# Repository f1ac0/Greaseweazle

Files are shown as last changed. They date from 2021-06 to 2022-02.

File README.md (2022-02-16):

# Greaseweazle
The Greaseweazle project by Keir Fraser is a USB floppy drive interface and software tool to read and write disk images to and from real floppies. It works at a low level so it can deal with formats that are unknown to the standard PC floppy disk controller.
https://github.com/keirf/Greaseweazle

The project in this repository is just a recreated "F1" board making use of the bare chips instead of a bluepill module, and designed to plug directly into a standard PC drive.
- It is small : it fits inside the 3.5" drive height and the ribbon width
- It is equipped with the female 34 pin connector to conveniently plug it in the drive, without a ribbon cable
- It connects to the PC with a micro USB cable
- It has a pass-through header for powering the drive (5v only). An external 5v/12v PSU is required only for drives requiring 12v or power hungry ones.
- It uses SMD stuff (maybe harder to solder)
- It is designed using the KiCAD EDA
- It works with the original "F1" Greaseweazle firmware and tool
- It is updated to support the DISKCHANGE signal and to be able to report as a "F1 plus" board. This is necessary for the WinUAE FloppyBridge plugin by Robert Smith (http://amiga.robsmithdev.co.uk/winuae) who added support to the Greaseweazle in addition to his original DrawBridge interface. Thank you !
- It does not have the "F7" features like double drive support

# Disclaimer
This is a hobbyist project, it comes with no warranty and no support.

This version is not endorsed by the original author, please don't bother him with issues you might have because of it.

I publish this work using the same license as the original : The Unlicense.

If you find it useful, please reward the original author.

# BOM
- 1x STM32F103C8T6 or CS32F103C8T6
- 1x 3.3v LDO, either SPX3819M5-L-3-3 or XC6206P332MR or equivalent
- 1x 8MHz HC-49 crystal
- 2x 1uF 0805 capacitors
- 3x 100nF 0805 capacitors
- 2x 22pf 0805 capacitors
- 2x 22 ohm 0805 resistors
- 1x 1K 0805 resistor
- 1x 10K 0805 resistor
- 1x 100K 0805 resistor (to reduce the BOM you can use a 10k)
- 1x 1K 0603x4 resistor array
- 1x optional 0805 LED and 0805 resistor (330 ohm or more)
- 1x Micro USB Female Socket B type
- 1x 2x17 2.54mm pin socket
- 1x FDD power cable

# Making it
Check for shorts at least between 5V, 3.3V, and GND traces before applying power !

The programming port does not need to be soldered since it needs to be programmed just once : you can just hold it in place during the few seconds required for programming.

For the software part, it works with the original "F1" firmware and tool.

There are ID pads on the bottom of the board :
- with ID pads left open, it will be identified as a "F1" version.
- recommended for FloppyBridge plugin : use a recent firmware and close ID0 on the "2" side, make sure the "1" side is open, then it will be identified as a "F1 plus".

To program the uC, I personally use a STLINK clone dongle with the stlink tool : https://github.com/stlink-org/stlink
```
st-flash --format ihex write Greaseweazle-F1-v0.??.hex
```
To update through the USB cable, bridge CK and GND on the programming port before connecting the USB cable, then enter
```
Greaseweazle/gw update
```

# Using it
Choose a PC drive. Do not use a Shugart drive from your Amiga. Prefer a 5v one that does not require a 12V rail.
- Plug the board to the 34 pin connector of the PC drive,
- If your drive is 5v only, plug the power cord from the Greaseweazle board to the power plug of the drive,
- If the drive needs 12v, or if your USB source does not deliver enough current, then use an external power supply instead,
- Plug a micro USB cable to the device,
- Then install it and use it like an original Greaseweazle device : https://github.com/keirf/Greaseweazle/wiki/Software-Installation
```
Greaseweazle/gw read mydisk.scp
Greaseweazle/gw write mydisk.scp
```

To use it with WinUAE, see : http://amiga.robsmithdev.co.uk/winuae

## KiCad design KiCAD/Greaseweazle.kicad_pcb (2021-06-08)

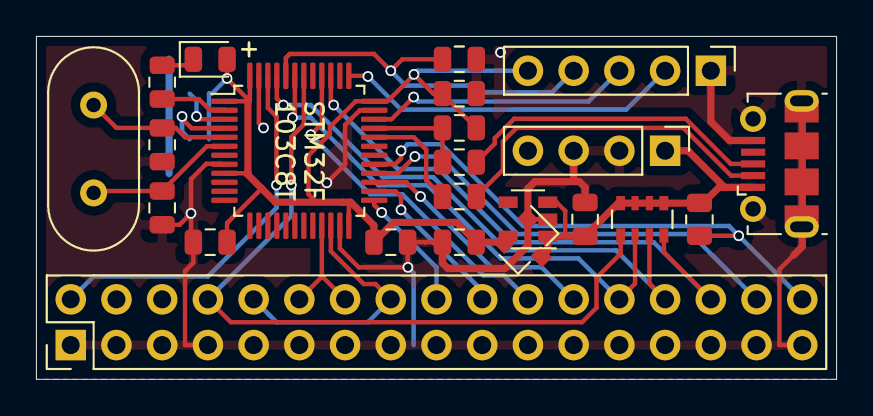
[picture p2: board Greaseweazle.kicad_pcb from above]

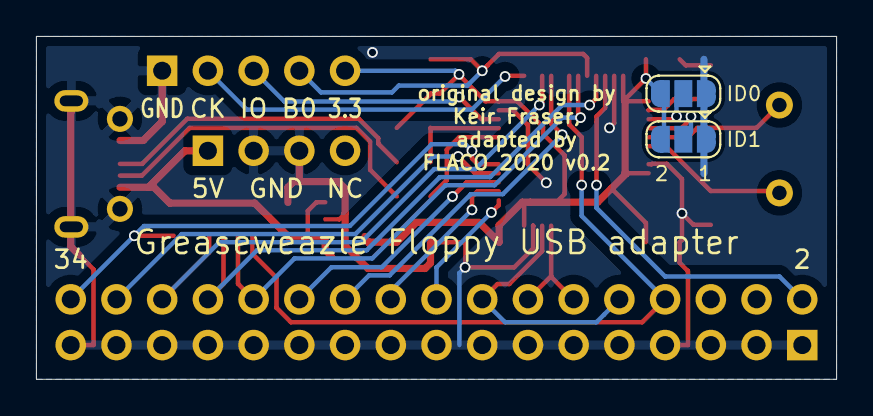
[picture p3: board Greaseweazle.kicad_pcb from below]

Board: 2 copper layers, 44.5 x 19.0 mm, 25 parts (2 on the bottom side), 29 nets.

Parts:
C1, C2: 22p; C_0805_2012Metric
C4, C5: 1u; C_0805_2012Metric
C6, C7, C8: 100n; C_0805_2012Metric
D1: Blue; LED_0805_2012Metric
J1: USB_B_Micro; USB_Micro-B_Molex-105017-0001
J2: PROG; PinHeader_1x05_P2.54mm_Vertical
J3: POWER; PinHeader_1x04_P2.54mm_Vertical
J4: Conn_02x17_Odd_Even; PinHeader_2x17_P2.54mm_Vertical
JP1: ID0; SolderJumper-3_P1.3mm_Open_RoundedPad1.0x1.5mm
JP2: ID1; SolderJumper-3_P1.3mm_Open_RoundedPad1.0x1.5mm
R2: 510; R_0805_2012Metric
R3: 100k; R_0805_2012Metric
R4: 1k; R_0805_2012Metric
R5: 10k; R_0805_2012Metric
R6, R7: 22; R_0805_2012Metric
RN1: 1k; R_Array_Convex_4x0603
U1: SPX3819M5-L-3-3; SOT-23-5
U2: STM32F103C8Tx; LQFP-48_7x7mm_P0.5mm
U3: XC6206PxxxMR; SOT-23
Y1: 8M; Crystal_HC49-U_Vertical

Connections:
+3V3: C5.1, C6.1, C7.1, C8.1, D1.2, J2.5, JP1.3, JP2.3, R5.1, U1.5, U2.1, U2.9, U2.24, U2.36, U2.48, U3.2
+5V: C4.1, J1.1, J3.1, R4.1, RN1.5, RN1.6, RN1.7, RN1.8, U1.1, U1.3, U3.3
/BOOT0: J2.4, R3.1, U2.44
/ID0: JP1.2, U2.3
/ID1: JP2.2, U2.4
/LED: R2.2, U2.2
/SWCLK: J2.2, U2.37
/SWDIO: J2.3, U2.34
/USB_D+: J1.3, R7.1
/USB_D-: J1.2, R6.1
/_DENSEL: J4.2, U2.46
/_DIR: J4.18, U2.25
/_DKRD: J4.30, RN1.4, U2.39
/_DKWD: J4.22, U2.40
/_DKWE: J4.24, U2.27
/_DSKCHG: J4.34, R4.2, U2.29
/_INDEX: J4.8, RN1.1, U2.42
/_MTR: J4.10, J4.16, U2.22
/_SEL: J4.12, J4.14, U2.21
/_SIDE: J4.32, U2.28
/_STEP: J4.20, U2.26
/_TRK0: J4.26, RN1.2, U2.43
/_WRPROT: J4.28, RN1.3, U2.45
GND: C1.2, C2.2, C4.2, C5.2, C6.2, C7.2, C8.2, J1.5, J1.6, J2.1, J3.2, J3.3, J4.1, J4.3, J4.5, J4.7, J4.9, J4.11, J4.13, J4.15, J4.17, J4.19, J4.21, J4.23, J4.25, J4.27, J4.29, J4.31, J4.33, JP1.1, JP2.1, R3.2, U1.2, U2.8, U2.23, U2.35, U2.47, U3.1
unnamed: C1.1, U2.5, Y1.1
unnamed: C2.1, U2.6, Y1.2
unnamed: D1.1, R2.1
unnamed: R5.2, R7.2, U2.33
unnamed: R6.2, U2.32

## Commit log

2020-07-31 Respository init with v0.1 KiCAD files, Readme and License
    [Greaseweazle.kicad_pcb, Greaseweazle.sch]
2021-06-08 Kicad : 0.2 with additional regulator footprint, DISKCHANGE signal and ID jumpers
    [Greaseweazle.kicad_pcb, Greaseweazle.sch]

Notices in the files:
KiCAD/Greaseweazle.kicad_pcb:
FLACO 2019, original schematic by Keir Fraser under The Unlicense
